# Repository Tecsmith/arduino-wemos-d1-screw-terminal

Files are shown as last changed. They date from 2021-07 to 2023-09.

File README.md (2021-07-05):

# Screw terminal board for Wemos / LOLIN D1 Mini / Mini Pro

| Board | URL |
|---|---|
| [Wemos / LOLIN D1 Mini Screw Terminal Breakout](https://tecsmith.github.io/arduino-wemos-d1-screw-terminal/) |  [`c1k.it/d1m1`](http://c1k.it/d1m1) |

## Help, About, *etc.*

Refer to the [docs folder](docs/index.md).

<p align="center" style="color:#069">★</p>

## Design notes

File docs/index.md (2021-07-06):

# Wemos / LOLIN D1 Mini Screw Terminal Breakout

**Wemos / LOLIN D1 Mini / Mini Pro Screw Terminal Breakout**, for mounting the [LOLIN D1 Mini](https://www.wemos.cc/en/latest/d1/d1_mini.html) board.

GitHub repository at [Tecsmith/arduino-wemos-d1-screw-terminal](https://github.com/Tecsmith/arduino-wemos-d1-screw-terminal/)

----------

## Specifications

- Simple breakout in the Qwiic board form factor exposing D1 Mini pins to screw terminals
- 2x Qwiic connectors (works with SparkFun's [Qwiic Connect System](https://www.sparkfun.com/qwiic))
- Standard I<sup>2</sup>C breakout pins
- Reset button and remote reset button via JST-PH-2 header
- Optional 5V Voltage Regulator for use with higher voltages
  - It's recommended to use a [Pololu 5V Step-Up/-Down V-Regulator S10V4F5](https://www.pololu.com/product/2121)
  - Must CUT JP1 if Voltage Regulator is used!!

----------

## On Board Jumpers

### JP1 - Optional 5V Voltage regulator (bottom)

Input voltage must abide by Wemos limit (ME6211 = 6V max), or you can solder in a 5V Voltage Regulator.

1. JP1 is by default TIED (shorting out V-Reg In and Out Pins).  This must be cut if the Voltage Regulator is installed.

2. One can also use the JP1 pins, with ties cut, as a remote ON/OFF switch (but with no Voltage Regulator).

### JP2 - I<sup>2</sup>C Pull Ups (top)

- Connected _(default)_: 4.7KΩ pullups
- Cut both sides: No pullups

### JP3 - LED Enable (top)

- Connected _(default)_: LED shows power state
- Cut: LED disabled

----------

## Manufacturing

* Schematic print: [wemos-d1-screw-terminal-v1.0.pdf](wemos-d1-screw-terminal-v1.0.pdf)
* Schematic source (in EAGLE): [Tecsmith/arduino-wemos-d1-screw-terminal/EAGLE/wemos-d1-screw-terminal-v1.0.sch](https://github.com/Tecsmith/arduino-wemos-d1-screw-terminal/blob/main/EAGLE/wemos-d1-screw-terminal-v1.0.sch)
* PCB design (in EAGLE): [Tecsmith/arduino-wemos-d1-screw-terminal/EAGLE/wemos-d1-screw-terminal-v1.0.brd](https://github.com/Tecsmith/arduino-wemos-d1-screw-terminal/blob/main/EAGLE/wemos-d1-screw-terminal-v1.0.brd)

| Top | Bottom |
|:---:|:---:|
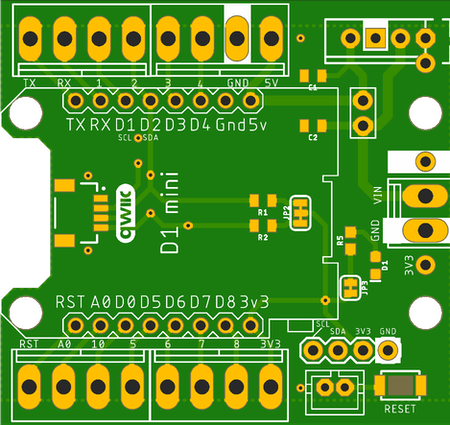
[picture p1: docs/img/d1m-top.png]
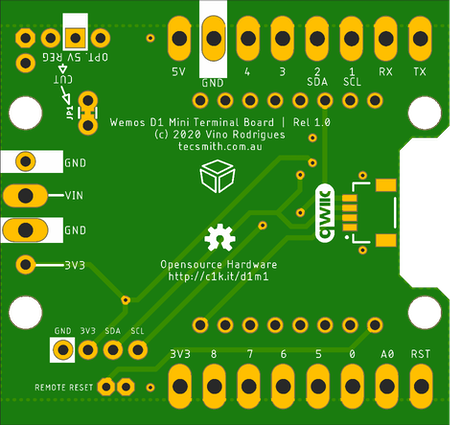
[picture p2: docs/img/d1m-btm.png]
|  |  |

<p align="center">Initial prototype built by JCLPCB</p>

----------
<p align="center" style="color:#069">★</p>

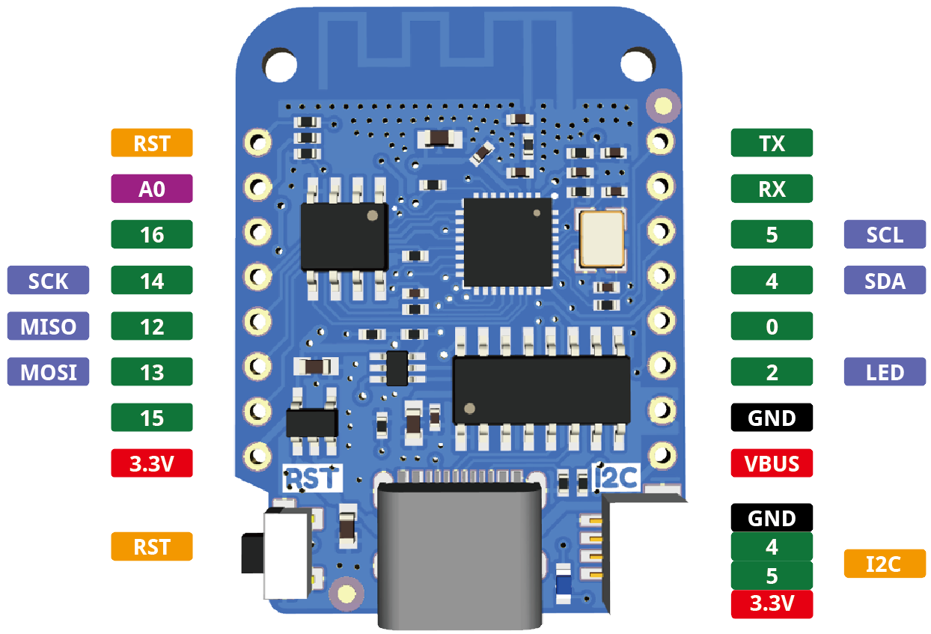
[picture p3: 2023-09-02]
docs/img/d1_mini_v4.0.0_5_16x9.png

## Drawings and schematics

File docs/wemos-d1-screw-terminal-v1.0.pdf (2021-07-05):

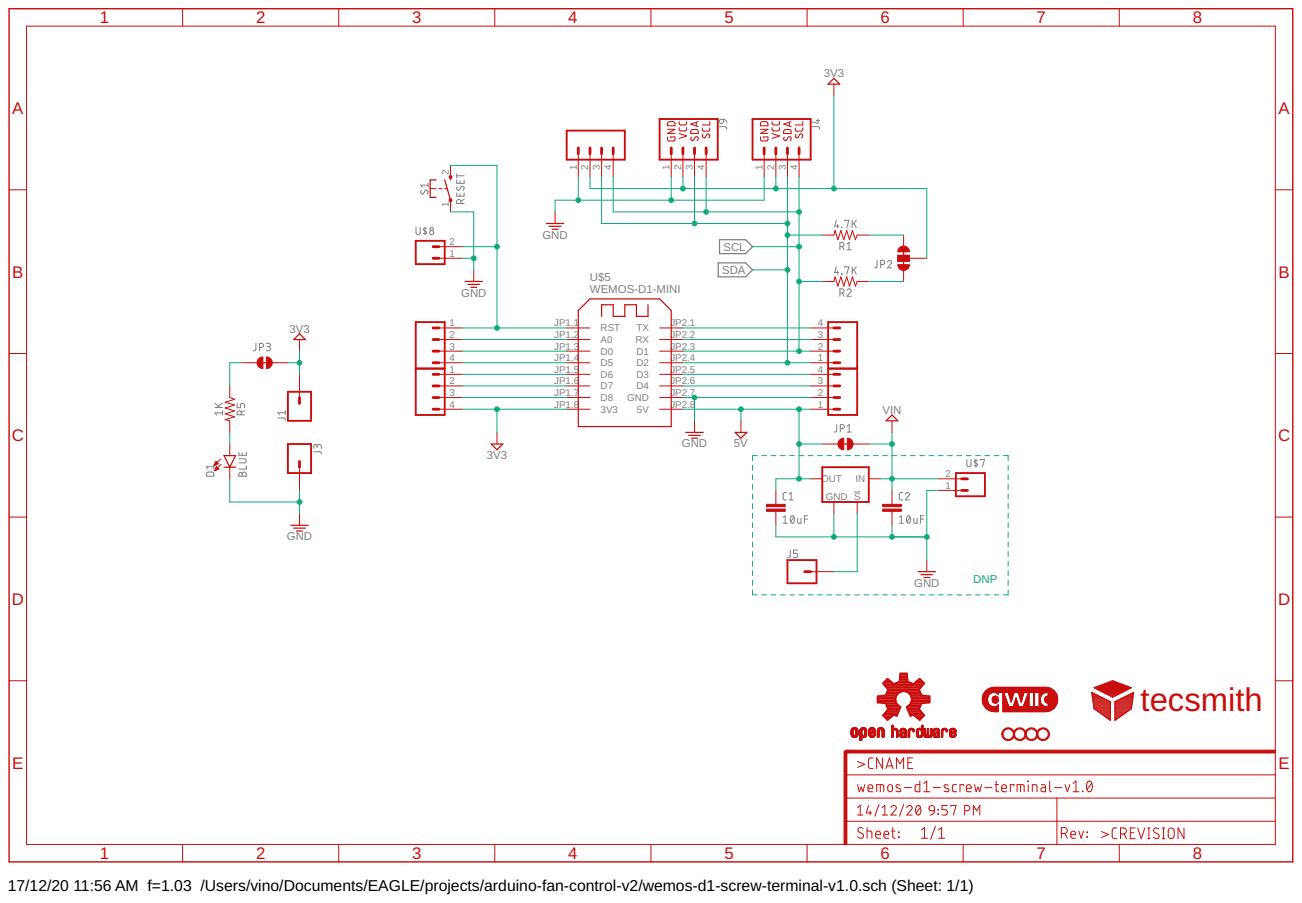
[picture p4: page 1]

JP2.2 D1 | 3
JP2.3 D2 | 2

17/12/20 11:56 AM f=1.03 /Users/vino/Documents/EAGLE/projects/arduino-fan-control-v2/wemos-d1-screw-terminal-v1.0.sch (Sheet: 1/1)

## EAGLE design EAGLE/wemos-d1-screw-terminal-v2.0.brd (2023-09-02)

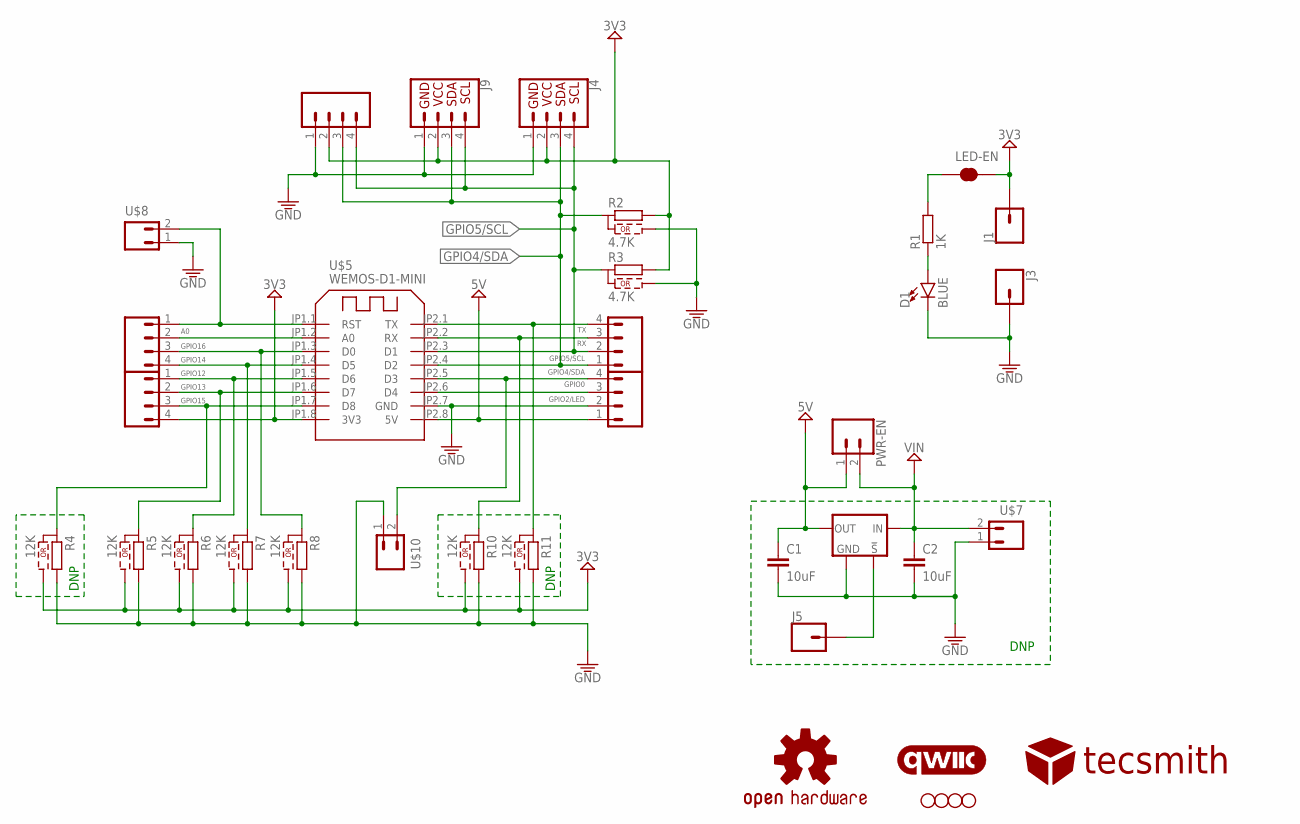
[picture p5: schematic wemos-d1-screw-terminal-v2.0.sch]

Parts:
C1, C2: 10uF; 0805
D1: BLUE; LED-0603
H1, H2, H5, H6: STAND-OFF
J1, J3, J5: CONN_01PTH_NO_SILK_YES_STOP; 1X01_NO_SILK
J2: CONN_04PTH; 1X04
J4, J9: QWIIC_RIGHT_ANGLE; JST04_1MM_RA
LED-EN: JUMPER-SMT_2_NC_TRACE_SILK; SMT-JUMPER_2_NC_TRACE_SILK
LOGO1: OSHW-LOGOS; OSHW-LOGO-S
LOGO2: QWIIC_LOGO_6MM; QWIIC_6MM
PWR-EN: CONN_021X02_NO_SILK; 1X02_NO_SILK
R1: 1K; R0603
R2, R3: 4.7K; R0603_JMP
R4, R5, R6, R7, R8, R10, R11: 12K; R0603_JMP
U$1, U$2, U$3, U$4: CON_04SCREW; WURTH_2431_3.5MM_4X_SCREW
U$5: WEMOS-D1-MINI
U$6: POLOLU-VREG; TO-220+1
U$7: CON_02SCREW; WURTH_2431_3.5MM_2X_SCREW
U$8, U$10: JST-PH-2; JST-PH2
U$9: TECSMITH-LOGO

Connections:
A0: U$1.2, U$5.JP1.2 (A0)
GND: C1.2, C2.2, D1.C, J2.1, J3.1, J4.1, J9.1, R2.3, R3.3, R4.2, R5.2, R6.2, R7.2, R8.2, R10.2, R11.2, U$3.2, U$5.JP2.7 (GND), U$6.GND, U$7.1, U$8.1, U$10.1
GPIO0: U$3.4, U$5.JP2.5 (D3), U$10.2
GPIO2/LED: U$3.3, U$5.JP2.6 (D4)
GPIO4/SDA: J2.3, J4.3, J9.3, R2.1, U$4.1, U$5.JP2.4 (D2)
GPIO5/SCL: J2.4, J4.4, J9.4, R3.1, U$4.2, U$5.JP2.3 (D1)
GPIO12: R6.1, U$2.1, U$5.JP1.5 (D6)
GPIO13: R5.1, U$2.2, U$5.JP1.6 (D7)
GPIO14: R7.1, U$1.4, U$5.JP1.4 (D5)
GPIO15: R4.1, U$2.3, U$5.JP1.7 (D8)
GPIO16: R8.1, U$1.3, U$5.JP1.3 (D0)
unnamed: D1.A, R1.1
unnamed: LED-EN.1, R1.2
unnamed: J5.1, U$6.!SHDN
RST: U$1.1, U$5.JP1.1 (RST), U$8.2
RX: R10.1, U$4.3, U$5.JP2.2 (RX)
TX: R11.1, U$4.4, U$5.JP2.1 (TX)
VCC: J1.1, J2.2, J4.2, J9.2, LED-EN.2, R2.2, R3.2, R4.3, R5.3, R6.3, R7.3, R8.3, R10.3, R11.3, U$2.4, U$5.JP1.8 (3V3)
VCC_1: C1.1, PWR-EN.1, U$3.1, U$5.JP2.8 (5V), U$6.OUT
VCC_2: C2.1, PWR-EN.2, U$6.IN, U$7.2

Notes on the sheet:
DNP

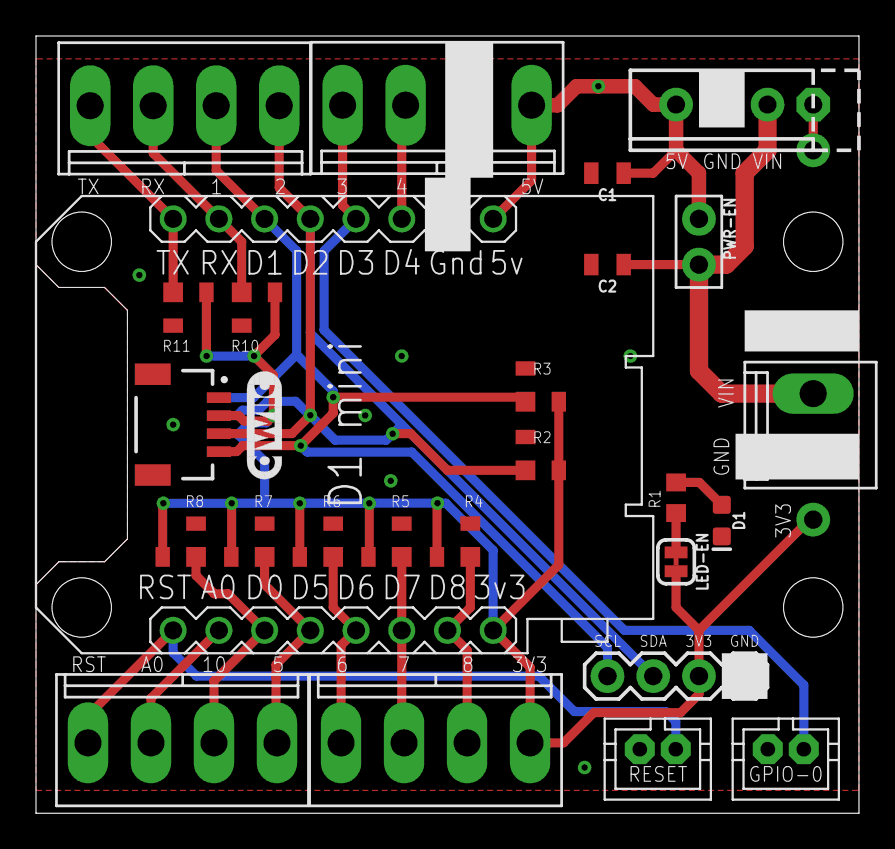
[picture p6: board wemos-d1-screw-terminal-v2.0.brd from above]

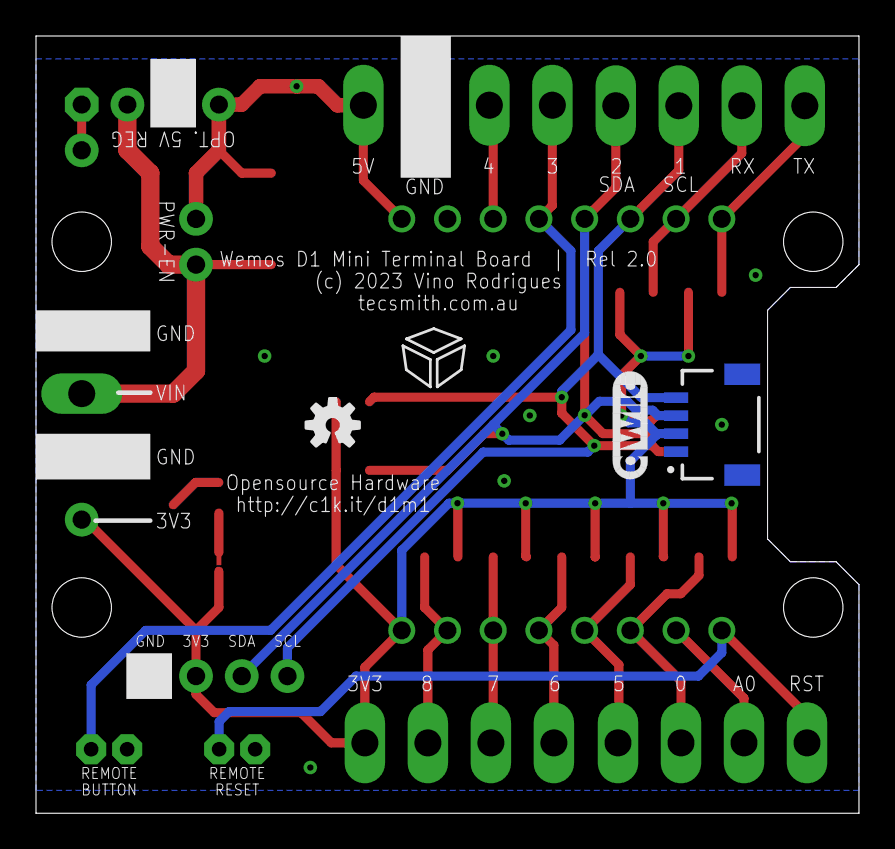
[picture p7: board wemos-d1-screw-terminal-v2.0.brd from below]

Board: 2 copper layers, 45.7 x 43.2 mm, 38 parts (4 on the bottom side), 20 nets.

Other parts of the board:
LOGO3: QWIIC_LOGO_6MM; QWIIC_6MM

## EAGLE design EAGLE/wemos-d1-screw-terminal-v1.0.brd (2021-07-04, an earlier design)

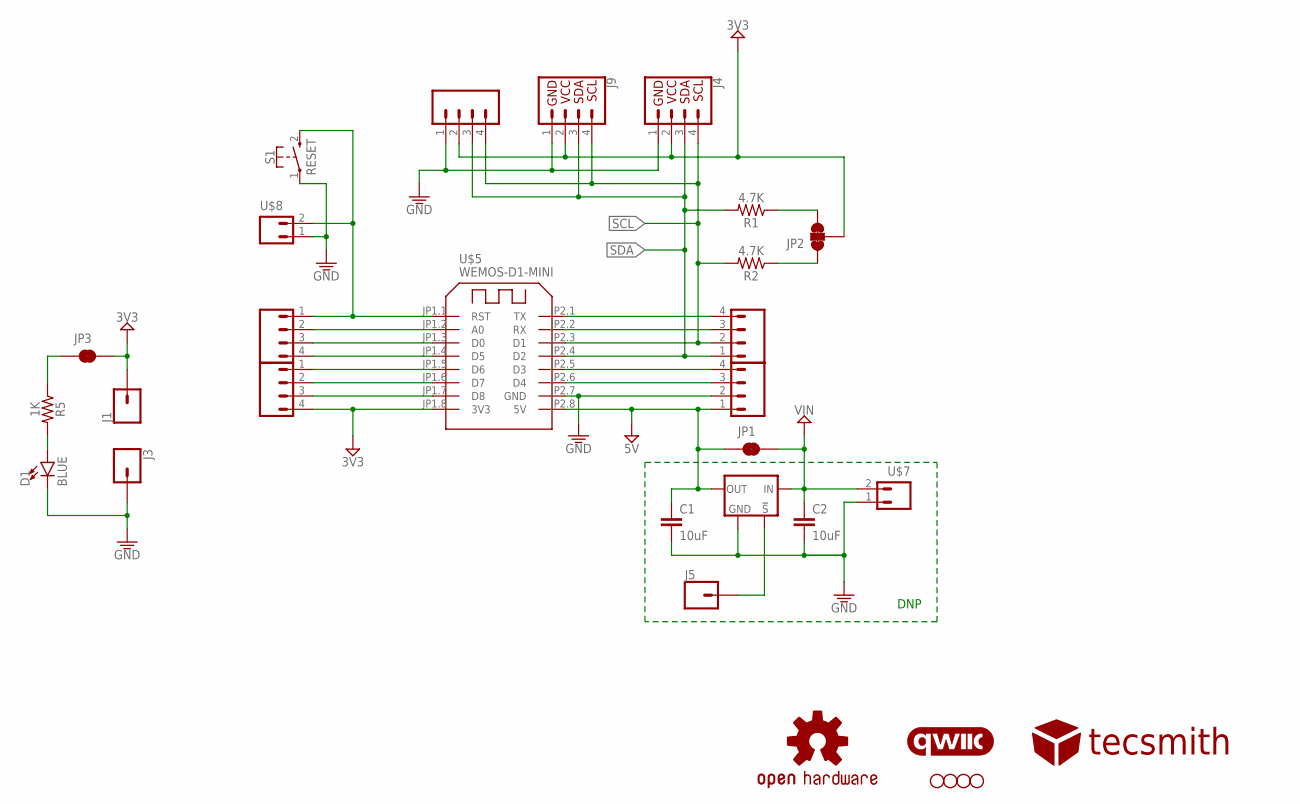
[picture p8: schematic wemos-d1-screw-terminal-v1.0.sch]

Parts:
C1, C2: 10uF; 0805
D1: BLUE; LED-0603
H1, H2, H5, H6: STAND-OFF
J1, J3, J5: CONN_01PTH_NO_SILK_YES_STOP; 1X01_NO_SILK
J2: CONN_04PTH; 1X04
J4, J9: QWIIC_RIGHT_ANGLE; JST04_1MM_RA
JP1: JUMPER-COMBO_2_NC_TRACE; COMBO-JUMPER_2_NC_TRACE
JP2: JUMPER-SMT_3_2-NC_TRACE_SILK; SMT-JUMPER_3_2-NC_TRACE_SILK
JP3: JUMPER-SMT_2_NC_TRACE_SILK; SMT-JUMPER_2_NC_TRACE_SILK
LOGO1: OSHW-LOGOS; OSHW-LOGO-S
LOGO2: QWIIC_LOGO_6MM; QWIIC_6MM
R1, R2: 4.7K; 0805
R5: 1K; 0603
S1: RESET; SKRKAEE020
U$1, U$2, U$3, U$4: CON_04SCREW; WURTH_2431_3.5MM_4X_SCREW
U$5: WEMOS-D1-MINI
U$6: POLOLU-VREG; TO-220+1
U$7: CON_02SCREW; WURTH_2431_3.5MM_2X_SCREW
U$8: JST-PH-2; JST-PH2
U$9: TECSMITH-LOGO

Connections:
GND: C1.2, C2.2, D1.C, J2.1, J3.1, J4.1, J9.1, S1.1, U$3.2, U$5.JP2.7 (GND), U$6.GND, U$7.1, U$8.1
unnamed: S1.2 (3), U$1.1, U$5.JP1.1 (RST), U$8.2
unnamed: U$1.2, U$5.JP1.2 (A0)
unnamed: U$1.3, U$5.JP1.3 (D0)
unnamed: U$1.4, U$5.JP1.4 (D5)
unnamed: U$2.1, U$5.JP1.5 (D6)
unnamed: D1.A, R5.2
unnamed: U$2.2, U$5.JP1.6 (D7)
unnamed: U$2.3, U$5.JP1.7 (D8)
unnamed: JP3.1, R5.1
unnamed: U$4.4, U$5.JP2.1 (TX)
unnamed: U$4.3, U$5.JP2.2 (RX)
unnamed: J5.1, U$6.!SHDN
unnamed: U$3.4, U$5.JP2.5 (D3)
unnamed: U$3.3, U$5.JP2.6 (D4)
unnamed: JP2.1, R2.1
unnamed: JP2.3, R1.1
SCL: J2.4, J4.4, J9.4, R2.2, U$4.2, U$5.JP2.3 (D1)
SDA: J2.3, J4.3, J9.3, R1.2, U$4.1, U$5.JP2.4 (D2)
VCC: J1.1, J2.2, J4.2, J9.2, JP2.2, JP3.2, U$2.4, U$5.JP1.8 (3V3)
VCC_1: C1.1, JP1.1, JP1.3 (1), U$3.1, U$5.JP2.8 (5V), U$6.OUT
VCC_2: C2.1, JP1.2, JP1.4 (2), U$6.IN, U$7.2

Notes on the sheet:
DNP

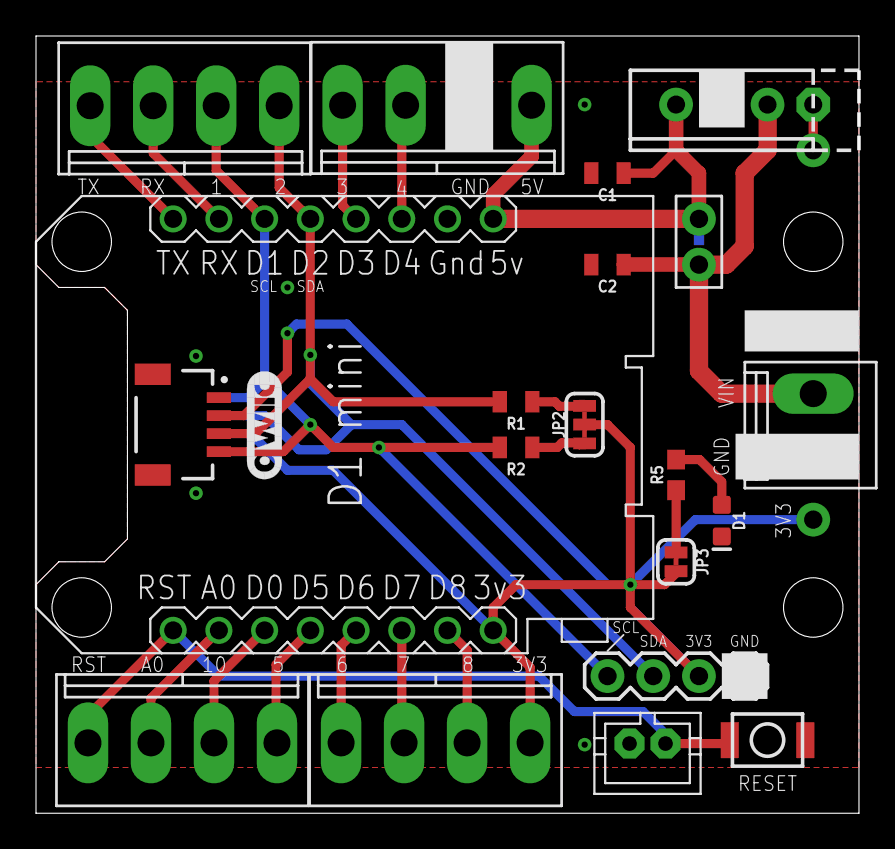
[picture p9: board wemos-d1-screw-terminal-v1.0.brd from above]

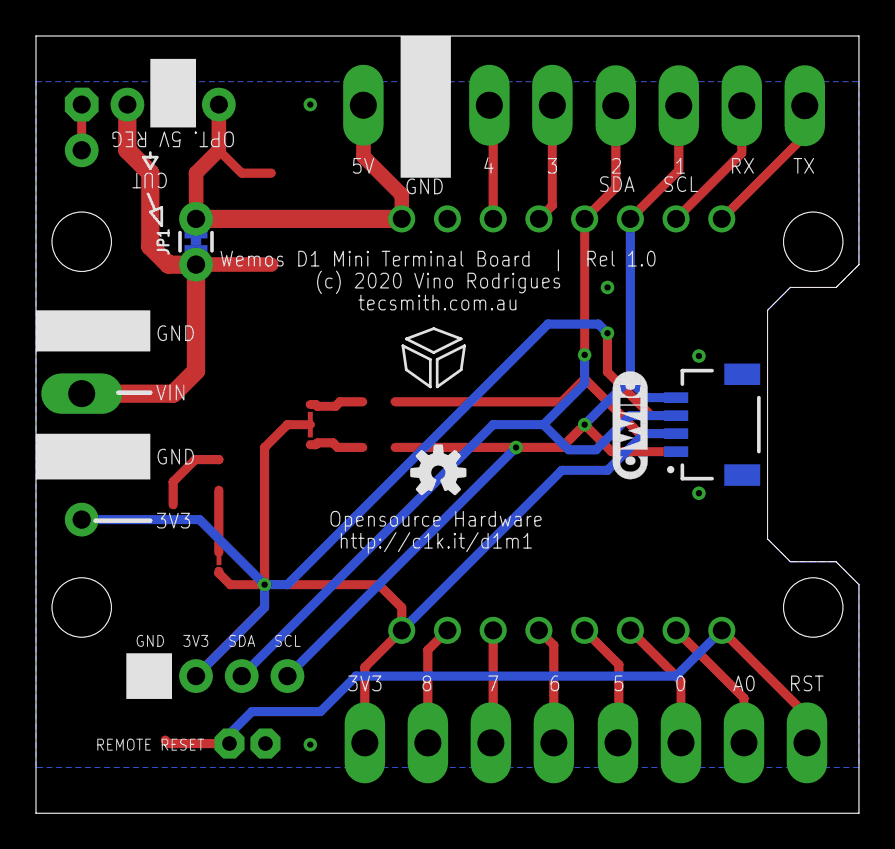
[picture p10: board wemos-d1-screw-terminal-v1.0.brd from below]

Board: 2 copper layers, 45.7 x 43.2 mm, 32 parts (5 on the bottom side), 22 nets.

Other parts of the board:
LOGO3: QWIIC_LOGO_6MM; QWIIC_6MM

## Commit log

2021-07-04 moved from fan-control project
    [wemos-d1-screw-terminal-v1.0.brd, wemos-d1-screw-terminal-v1.0.sch]
2021-07-05 move items from arduino-fan-control-v2 project
2023-09-02 Update to Rel 2.0
    [wemos-d1-screw-terminal-v2.0.brd, wemos-d1-screw-terminal-v2.0.sch]

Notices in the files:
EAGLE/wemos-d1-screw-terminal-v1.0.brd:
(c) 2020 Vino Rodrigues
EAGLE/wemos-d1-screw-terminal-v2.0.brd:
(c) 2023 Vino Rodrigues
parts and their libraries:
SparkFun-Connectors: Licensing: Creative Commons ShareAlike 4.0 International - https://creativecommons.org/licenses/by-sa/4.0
